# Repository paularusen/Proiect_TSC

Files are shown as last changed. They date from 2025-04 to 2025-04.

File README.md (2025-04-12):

## Descrierea produsului

  Proiectul este centrat pe microcontrolerul ```ESP32-C6```, care, datorită versatilității sale, suportă comunicații Wi‑Fi 6, 
Bluetooth și IEEE 802.15.4, alături de multiple interfețe periferice. Designul integrează un e‑paper display, un modul SD 
card, memorie flash externă, un modul RTC și interfețe de comunicație (```USB```, ```UART```, ```I2C```). Fiecare interfață este atribuită 
unor pini specifici pentru a asigura o separare clară a funcțiilor, evitând conflictele și maximizând performanța și
eficiența energetică.

## Diagrama bloc

Diagrama_bloc

## Descrierea componentelor și a pinilor utilizați

### ESP32-C6 – Microcontrolerul Central
Rol: Coordonează toate operațiunile sistemului și gestionează comunicațiile cu toate modulele periferice.
Pini atribuiți:

	- GND: 1 si 28
	- 3V3: 2
	- RESET: 3
	- SS_SD: 4
	- EPD_DC: 5
	- SCK: 6
	- MOSI: 7
	- INT_RTC: 8
	- 32KHZ: 9
	- GPIO8: 10
	- EPD_CS: 11
	- FLASH_CS: 12
	- USB_D-: 13
	- USB_D+: 14
	- IO/BOOT: 15
	- RTC_RST: 16
	- I2C_PW: 17
	- EPD_3V3_C: 18
	- SDA: 19
	- SCL: 20
	- EPD_RST: 21
	- IO/CHANGE: 23
	- RX: 24
	- TX: 25
	- EPD_BUSY: 26
	- MISO: 27

Rolul fiecărui pin va fi detaliat în cadrul componentelor, în următoarele rânduri.

### E‑Paper Display
Rol: Afișare informații într-un mod foarte eficient energetic, potrivit pentru aplicații de tip IoT sau afișaje statice.
Pini atribuiți:

	- EPD_DC: Selectează între modurile de comandă și de date pentru e-paper.
	- EPD_CS: Chip Select – activează comunicația cu e‑paper-ul.
	- EPD_RST: Linie de reset, esențială la inițializare pentru afișaj.
	- EPD_BUSY: Semnal de status ce indică dacă afișajul este ocupat (prevenind suprascrierea datelor).
	- EPD_3V3_C: Linia de alimentare dedicată, asigurând o tensiune stabilă și izolată pentru e‑paper.

### Modul SD Card
Rol: Stocare de date suplimentare (fișiere de sistem, date utilizator etc.)
Pini atribuiți:

	- SS_SD: Chip select specific pentru SD Card, activând modulul numai atunci când este necesar.
	- SCK: Linia de ceas pentru comunicațiile SPI.
	- MOSI: Linia de ieșire de date dinspre ESP32 către SD Card.
	- MISO: Linia de intrare de date, pentru citirea informațiilor de la SD Card.

### Memorie Flash Externă
Rol: Stocarea firmware-ului sau a datelor critice ce necesită o capacitate suplimentară față de memoria internă.
Pini atribuiți:

	- FLASH_CS: Chip select pentru memorie flash, pentru a activa comunicația doar atunci când este necesar.

### Modul RTC (Real-Time Clock)
Rol: Asigură o cronometrare precisă, utilă pentru funcții de alarmă, logare a datelor sau sincronizare de timp în 
aplicații IoT.
Pini atribuiți:

	- INT_RTC: Întrerupere de la RTC, notificând microcontrolerul despre evenimente (ex. alarmă).
	- RTC_RST: Linia de reset pentru modulul RTC, asigurând reinițializarea corectă a ceasului.
	- 32KHZ: Furnizează un semnal de 32 kHz, esențial pentru funcționarea precisă a RTC-ului.

### Senzorul de mediu (ex.: BME688):
Rol: Măsoară parametri esențiali precum temperatura, umiditatea, presiunea atmosferică și compoziția gazelor din mediul 
înconjurător.
Comunicarea se realizează prin magistrala I2C, utilizând SDA(linia de date I2C), SCL(linia de ceas I2C) și I2C_PW.

### Interfața I2C
Rol: Comunicare cu senzori, module de monitorizare a bateriei, eventual RTC suplimentar sau alte periferice cu consum 
redus.
Pini atribuiți:

	- SDA: Linia de date pentru comunicația I2C.
	- SCL: Linia de ceas pentru I2C.
	- I2C_PW: Poate fi folosit pentru a activa sau alimenta circuitele periferice I2C (ex. senzori sau monitor de baterie).

### Interfața USB
Rol: Programare, transfer de date sau alimentare în anumite condiții.
Pini atribuiți:

	- USB_D- și USB_D+: Linii diferențiale pentru comunicația USB.

### Interfața UART
Rol: Comunicații seriale pentru debugging, logare sau control extern.
Pini atribuiți:

	- RX: Recepție UART.
	- TX: Transmisie UART.

Pinii speciali precum IO/BOOT și IO/CHAGE permit configurarea modului de pornire și monitorizarea încărcării, iar GP0IO8 
și GOL asigură flexibilitatea pentru extinderi viitoare.
	IO/BOOT: utilizat la pornirea sistemului pentru selectarea modului de boot. Această funcție este esențială pentru a 
intra în modul de programare sau diagnosticare, conform cerințelor de firmware.
	IO/CHAGE: dedicat monitorizării stării de încărcare a sistemului. Acest pin poate fi legat la un circuit de detecție al 
încărcării bateriei sau indicator LED pentru a semnala starea de încărcare.
	GP0IO8: un GPIO general care poate fi folosit pentru extinderi ulterioare (ex. conectarea unui senzor adițional, trigger 
de eveniment etc.).
	Pin 22: funcționalitatea acestui pin poate fi folosită ca ieșire generală pentru semnale de control, cum ar fi activarea 
unor relee, indicatori LED suplimentari sau semnale de sincronizare pentru alte module.

## Consumul de Energie și comunicațiile

### Consumul microcontrolerului:
	- ESP32-C6 dispune de moduri de economisire a energiei (deep sleep) și este optimizat pentru aplicații IoT. Astfel, în 
condiții de standby consumul poate fi redus la câțiva microamperi.

### SPI și I2C:
	- Utilizarea magistralelor SPI (pentru SD Card, flash extern și e‑paper display) și I2C (pentru senzori și monitorizare 
baterie) permite un transfer de date rapid și eficient, dar și o separare logică care contribuie la reducerea 
interferențelor.

### USB și UART:
	- Aceste interfețe sunt folosite mai ales pentru debugging și programare. Deși USB poate implica un consum mai mare când 
este activ, acesta este activ doar în timpul programării sau transferurilor de date.

### Alimentare:
	- Pinul de 3V3) este utilizat pentru alimentarea ESP32-C6 și a modulelor critice, iar alocarea separată pentru EPD 
(EPD_3V3_C) asigură o tensiune stabilă pentru afișajul e-paper.

## Bill of Materials
| Componentă | Distribuitor | Datasheet |
| :--- | :--- | :--- |
| ESP32 C6| https://eu.mouser.com/ProductDetail/Espressif-Systems/ESP32-C6-WROOM-1U-N8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 | https://eu.mouser.com/datasheet/2/891/Espressif_Systems_7_11_2023_esp32_c6_wroom_1_wroom-3236277.pdf |
| BUTTON | https://www.digikey.ro/en/products/detail/bourns-inc/7914S-1-000E/2537971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 | https://www.bourns.com/docs/Product-Datasheets/7914.pdf |
| USB-C connector| https://eu.mouser.com/ProductDetail/Same-Sky/UJC-H-G-SMT-2-P6-TR?qs=IKkN%2F947nfApFV8T6rOqww%3D%3D |https://eu.mouser.com/datasheet/2/1628/ujc_h_g_smt_2_p6_tr-3511211.pdf |
| USBLC6-2SC6Y | https://eu.mouser.com/ProductDetail/STMicroelectronics/USBLC6-2SC6Y?qs=gNDSiZmRJS%2FOgDexvXkdow%3D%3D | https://eu.mouser.com/datasheet/2/389/usblc6_2sc6y-1852505.pdf |
| DMG2305UX-7 | https://eu.mouser.com/ProductDetail/Diodes-Incorporated/DMG2305UX-7?qs=L1DZKBg7t5F%2FNBHrjfxC%252Bg%3D%3D | https://www.diodes.com/assets/Datasheets/DMG2305UX.pdf |
| XC6220A331MR-G | https://eu.mouser.com/ProductDetail/Torex-Semiconductor/XC6220A331MR-G?qs=AsjdqWjXhJ8ZSWznL1J0gg%3D%3D | https://eu.mouser.com/datasheet/2/760/xc6220-3371556.pdf |
| SD0805S020S1R0 | https://eu.mouser.com/ProductDetail/KYOCERA-AVX/SD0805S020S1R0?qs=jCA%252BPfw4LHbpkAoSnwrdjw%3D%3D | https://eu.mouser.com/datasheet/2/40/schottky-3165252.pdf |
| 112A-TAAR-R03 | https://store.comet.srl.ro/Catalogue/Product/43497/ | https://store.comet.bg/download-file.php?id=27596 |
| 68uH inductance | https://eu.mouser.com/ProductDetail/Vishay-Dale/IFDC5050JZER680M?qs=iLKYxzqNS745SePZd8tBoA%3D%3D | https://www.vishay.com/docs/34635/ifdc5050jz.pdf |
| SI1308EDL-T1-GE3 | https://eu.mouser.com/ProductDetail/Vishay-Semiconductors/SI1308EDL-T1-GE3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 | https://www.vishay.com/docs/63399/si1308edl.pdf |
| MBR0530 | https://eu.mouser.com/ProductDetail/Micro-Commercial-Components-MCC/MBR0530-TP?qs=KFo7JewZbUECRHkxGanrdg%3D%3D | https://eu.mouser.com/datasheet/2/258/MBR0520_MBR0580_SOD123_-2492194.pdf |
| MCP73831 | https://eu.mouser.com/ProductDetail/Microchip-Technology/MCP73831-2ACI-MC?qs=hH%252BOa0VZEiBneYTVdpuVdg%3D%3D | https://eu.mouser.com/datasheet/2/268/MCP73831_Family_Data_Sheet_DS20001984H-3441711.pdf |
| BME688 | https://eu.mouser.com/ProductDetail/Bosch-Sensortec/BME688?qs=IS%252B4QmGtzzqQoVDscqwx3A%3D%3D | https://eu.mouser.com/datasheet/2/783/bst_bme688_fl000-2307034.pdf |
| FH34SRJ-24S-0.5SH(99) | https://eu.mouser.com/ProductDetail/Hirose-Connector/FH34SRJ-24S-0.5SH99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 | https://eu.mouser.com/datasheet/2/185/FH34SRJ_24S_0_5SH_99__CL0580_1255_6_99_2DDrawing_0-1615044.pdf |
| BD5229G-TR | https://eu.mouser.com/ProductDetail/ROHM-Semiconductor/BD5229G-TR?qs=4kLU8WoGk0vvnhrrYwdszw%3D%3D | https://fscdn.rohm.com/en/products/databook/datasheet/ic/power/voltage_detector/bd52xxg-e.pdf |
| MAX17048G+T10 | https://eu.mouser.com/ProductDetail/Analog-Devices-Maxim-Integrated/MAX17048G%2bT10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 | https://eu.mouser.com/datasheet/2/609/MAX17048_MAX17049-3469099.pdf |
| DS3231SN# | https://eu.mouser.com/ProductDetail/Analog-Devices-Maxim-Integrated/DS3231SN?qs=1eQvB6Dk1vhUlr8%2FOrV0Fw%3D%3D | https://eu.mouser.com/datasheet/2/609/DS3231-3421123.pdf |
| CPH3225A | https://eu.mouser.com/ProductDetail/Seiko-Semiconductors/CPH3225A?qs=3etwrb1wR%252BhUOph6lAO7eg%3D%3D | https://eu.mouser.com/datasheet/2/360/Seiko_Instruments_MicroBattery_E_20230330_2024Jan_-3561061.pdf |
| PFMF.050.1 | https://eu.mouser.com/ProductDetail/Schurter/PFMF.050.2?qs=1auRipcfynCums5v1iucSA%3D%3D | https://eu.mouser.com/datasheet/2/358/typ_PFMF-1275918.pdf |
| Qwiic | https://eu.mouser.com/ProductDetail/Adafruit/4208?qs=PzGy0jfpSMtbScLbr0L5dw%3D%3D | https://learn.adafruit.com/introducing-adafruit-stemma-qt/technical-specs |
| W25Q512JVEIQ | https://eu.mouser.com/ProductDetail/Winbond/W25Q512JVEIQ?qs=l7cgNqFNU1jw6svr3at6tA%3D%3D | https://eu.mouser.com/datasheet/2/949/Winbond_W25Q512JV_Datasheet-3240039.pdf |
| PGB1010603MR | https://eu.mouser.com/ProductDetail/Littelfuse/PGB1010603MR?qs=gu7KAQ731URLg4GSnNNN7Q%3D%3D | https://www.littelfuse.com/assetdocs/pulseguard-esd-suppressors-pgb1-datasheet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 |
| TANT Capacitor | https://eu.mouser.com/ProductDetail/KEMET/T491B107M006AT?qs=U312oeP%2FpiHOgyk6KO2m0g%3D%3D | https://www.vishay.com/docs/40002/293d.pdf |
| Capacitor 0.1uF | https://eu.mouser.com/ProductDetail/KYOCERA-AVX/KGF21BR71H104KT?qs=Jm2GQyTW%2FbjYyKCvVWAEOw%3D%3D | https://eu.mouser.com/datasheet/2/40/KGF-3223650.pdf |
| Capacitor 1uF | https://eu.mouser.com/ProductDetail/TAIYO-YUDEN/MAASL105CC7105MFCA01?qs=HFfMDpzxxd1Fn%2FInbJA7vw%3D%3D | https://eu.mouser.com/datasheet/2/396/TAIYO_YUDEN_04_27_2024_c_mlcc_A_e1-3451516.pdf |
| Capacitor 4.7uF | https://eu.mouser.com/ProductDetail/KYOCERA-AVX/CM05X5R475M16AH?qs=doiCPypUmgFT1xquZKhWtQ%3D%3D | https://eu.mouser.com/datasheet/2/40/Kyocera_AVX_Components_CM025_CM05_CM105_CM21_E217K-2932876.pdf |
| Capacitor 10 uF | https://eu.mouser.com/ProductDetail/TDK/CGA3EDX7T1A106M080AU?qs=ZcfC38r4PovL%2FBNBUzzBFw%3D%3D | https://product.tdk.com/system/files/dam/doc/product/capacitor/ceramic/mlcc/catalog/mlcc_automotive_general_en.pdf |
| Capacitor 100nF | https://eu.mouser.com/ProductDetail/KYOCERA-AVX/KAM21BR71H104JT?qs=Jm2GQyTW%2Fbic6Zk4McEt6w%3D%3D | https://eu.mouser.com/datasheet/2/40/AutoMLCCKAM-3216307.pdf |
| Resistor 0.47 | https://eu.mouser.com/ProductDetail/SEI-Stackpole/RNCL1210FT50L0?qs=17ckDYBRdelVLOJ%252BDFjlUw%3D%3D | https://eu.mouser.com/datasheet/2/385/sei_rncl-3223524.pdf |
| Resistor 2.2 | https://eu.mouser.com/ProductDetail/YAGEO/RT1206FRE072R2L?qs=XhSZopxZ3H6S0nYZD83pAA%3D%3D | https://eu.mouser.com/datasheet/2/447/PYu_RT_1_to_0_01_RoHS_L_15-3461507.pdf |
| Resistor 15 | https://eu.mouser.com/ProductDetail/Panasonic/ERA-6AHD150V?qs=MNPzkKEzRtQip8ZeekU%252BRw%3D%3D | https://industrial.panasonic.com/cdbs/www-data/pdf/RDM0000/AOA0000C307.pdf |
Resistor 200 | https://eu.mouser.com/ProductDetail/TE-Connectivity-Holsworthy/RP73C2B200RFTDF?qs=n4i9pByFsMR0dWGpf721CA%3D%3D | https://eu.mouser.com/datasheet/2/418/10/ENG_DS_1773272_M1-1588495.pdf |
| Resistor 2k | https://eu.mouser.com/ProductDetail/Panasonic/ERA-3AED202V?qs=yocZuyCaXdM2cBmjcGkIyA%3D%3D | https://industrial.panasonic.com/cdbs/www-data/pdf/RDM0000/AOA0000C307.pdf |
| Resistor 5k1 | https://eu.mouser.com/ProductDetail/Vishay-Beyschlag/MCS04020C5101FE000?qs=wTZ%2FFzl837YsKPLPRIXUbg%3D%3D | https://www.vishay.com/docs/28705/mcx0x0xpro.pdf |
| Resistor 10k | https://eu.mouser.com/ProductDetail/SEI-Stackpole/RNWA0612BTE10K0?qs=IKkN%2F947nfD62pDKWE9ZTQ%3D%3D | https://eu.mouser.com/datasheet/2/385/SEI_RNWA-3473840.pdf |
| Resistor 100K | https://eu.mouser.com/ProductDetail/Panasonic/ERA-3AED104V?qs=MNPzkKEzRtQIWcmUWL4kjg%3D%3D | https://industrial.panasonic.com/cdbs/www-data/pdf/RDM0000/AOA0000C307.pdf |
| E-Paper Display | https://eu.mouser.com/ProductDetail/Microtips-Technology/MT-DEPG0750BNU590F1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| https://eu.mouser.com/datasheet/2/271/MT_DEPG0750BNU590F1_V2_7-1894282.pdf |
| LP584174 Battery| https://www.tme.eu/en/details/accu-lp584174_cl/rechargeable-batteries/cellevia-batteries/l584174/ | https://www.tme.eu/Document/e0683d8c34e6d878124489f71bffb6ee/cel0014.pdf |

## Observații
- Am modificat footprint-ul componentei J2, prin mutarea pad-urilor GND, VUSB și B8 cu câțiva mm spre stânga, pentru a corecta eroarea ”SMD Hole”.

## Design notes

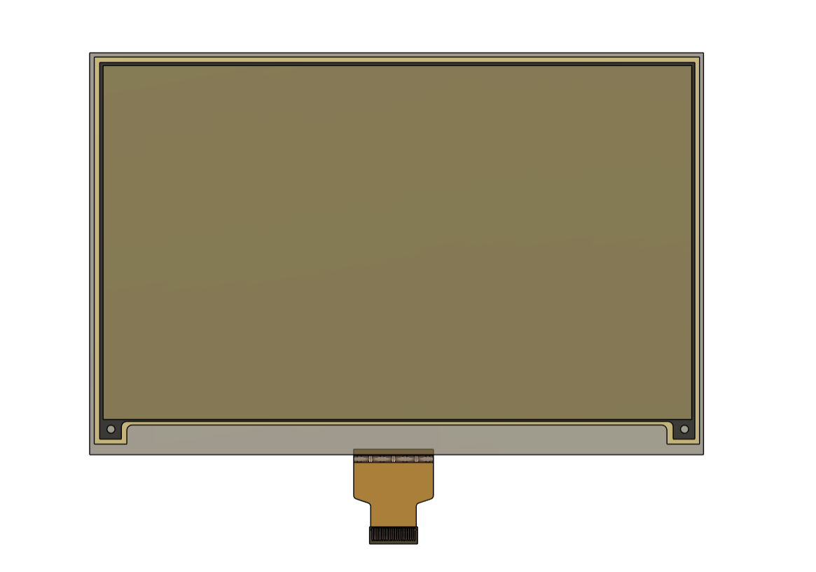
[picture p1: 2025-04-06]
Images/display_back.png

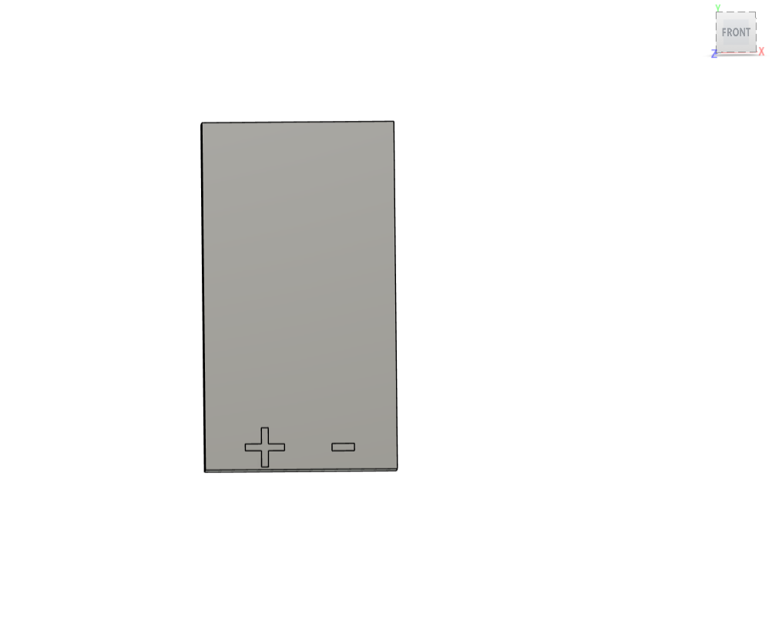
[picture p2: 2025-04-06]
Images/battery.png

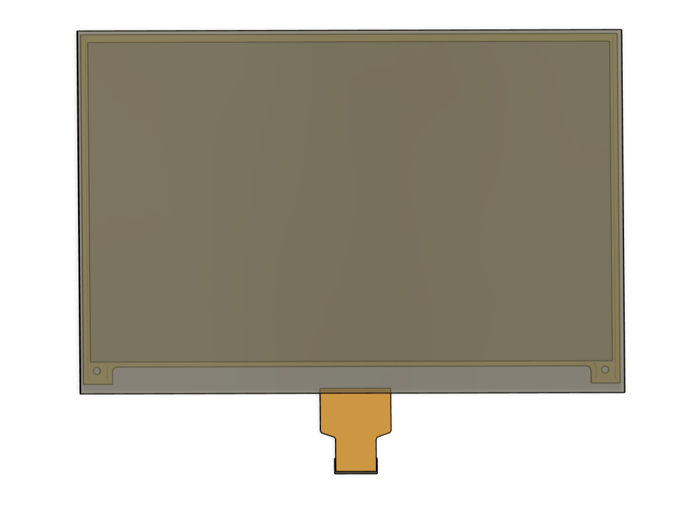
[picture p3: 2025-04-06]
Images/display_front.png

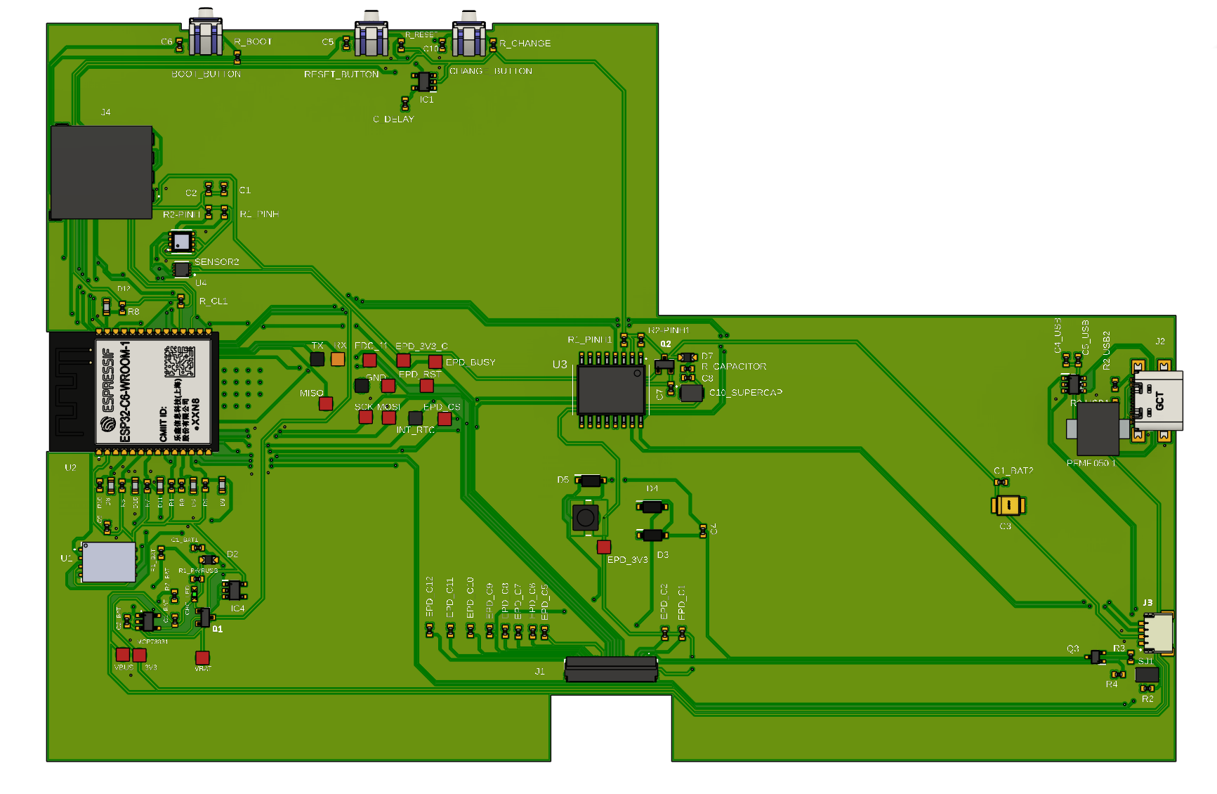
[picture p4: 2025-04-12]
Images/3D_board.png

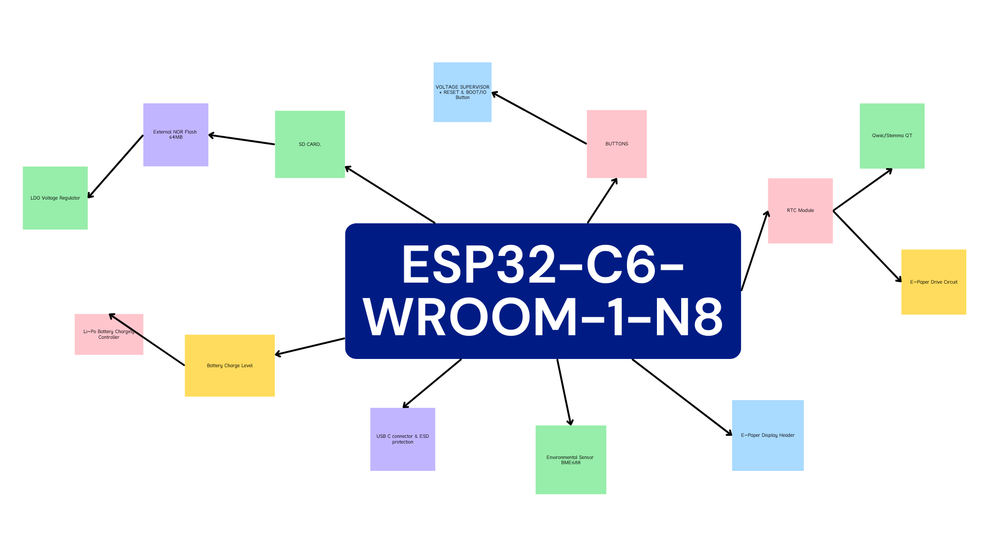
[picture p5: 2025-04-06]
Images/Diagrama_bloc.png

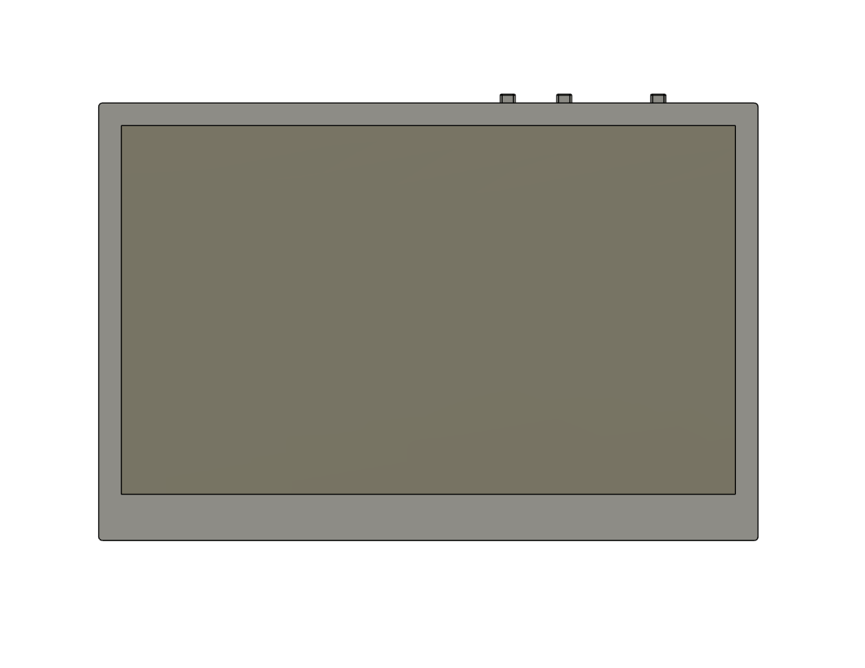
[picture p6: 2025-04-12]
Images/3D_device.png

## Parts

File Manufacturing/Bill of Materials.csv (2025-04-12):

Qty | Value | Device | Package | Parts | Description | ARROW_PART_NUMBER | ARROW_PRICE-STOCK | AVAILABILITY | CENTROID_NOT_SPECIFIED | CHECK_PRICES | COPYRIGHT | DATASHEET | DESCRIPTION | DIGIKEY_DESCRIPTION | DIGIKEY_PART_NUMBER | HEIGHT | LEAD_FREE | MANUFACTURER_NAME | MANUFACTURER_PART_NUMBER | MF | MFR_NAME | MOUSER_PART_NUMBER | MOUSER_PRICE-STOCK | MOUSER_TESTING_PART_NUMBER | MOUSER_TESTING_PRICE-STOCK | MP | MPN | PACKAGE | POPULARITY | PREFIX | PRICE | PROD_ID | PURCHASE-URL | ROHS | SNAPEDA_LINK | SPICEMODEL | SPICEPREFIX | TEMPERATURE_RANGE_HIGH | TEMPERATURE_RANGE_LOW | TP_SIGNAL_NAME | VALUE
1 |  | ADAFRUIT_LEDCHIP-LED0603 | ADAFRUIT_CHIP-LED0603 | CHG_LED | LED
1 |  | ESP32_WROVER_EAGLE-LTSPICE_RR0402 | ESP32_WROVER_EAGLE-LTSPICE_R0402 | R_CAPACITOR | RESISTOR, European symbol |  |  |  |  |  |  |  |  |  |  |  |  |  |  |  |  |  |  |  |  |  |  |  |  |  |  |  |  |  |  | NONE | R
1 | 0 | SJ | SJ | SJ1 | SMD solder JUMPER |  |  |  |  |  |  |  |  |  |  |  |  |  |  |  |  |  |  |  |  |  |  |  | 3
1 | 0.1uF/50V | ESP32_WROVER_EAGLE-LTSPICE_CC0402 | ESP32_WROVER_EAGLE-LTSPICE_C0402 | EPD_C5 | CAPACITOR, European symbol |  |  |  |  |  |  |  |  |  |  |  |  |  |  |  |  |  |  |  |  |  |  |  |  |  |  |  |  |  |  | NONE | C
1 | 0.47 | ESP32_WROVER_EAGLE-LTSPICE_RR0402 | ESP32_WROVER_EAGLE-LTSPICE_R0402 | R3 | RESISTOR, European symbol |  |  |  |  |  |  |  |  |  |  |  |  |  |  |  |  |  |  |  |  |  |  |  |  |  |  |  |  |  |  | NONE | R
1 | 100K | ESP32_WROVER_EAGLE-LTSPICE_RR0402 | ESP32_WROVER_EAGLE-LTSPICE_R0402 | R1_PWRUSB | RESISTOR, European symbol |  |  |  |  |  |  |  |  |  |  |  |  |  |  |  |  |  |  |  |  |  |  |  |  |  |  |  |  |  |  | NONE | R
1 | 100nF | EAGLE-LTSPICE_CC0402 | EAGLE-LTSPICE_C0402 | C4_USB | CAPACITOR, European symbol |  |  |  |  |  |  |  |  |  |  |  |  |  |  |  |  |  |  |  |  |  |  |  |  |  |  |  |  |  |  | NONE | C
7 | 100nF | ESP32_WROVER_EAGLE-LTSPICE_CC0402 | ESP32_WROVER_EAGLE-LTSPICE_C0402 | C1, C2, C6, C8, C9, C10, C_DELAY | CAPACITOR, European symbol |  |  |  |  |  |  |  |  |  |  |  |  |  |  |  |  |  |  |  |  |  |  |  |  |  |  |  |  |  |  | NONE | C
1 | 100uF | RCL_CPOL-EUCT3528 | RCL_CT3528 | C3 | POLARIZED CAPACITOR, European symbol |  |  |  |  |  |  |  |  |  |  |  |  |  |  |  |  |  |  |  |  |  |  |  | 0 |  |  |  |  |  |  |  | C
16 | 10K | ESP32_WROVER_EAGLE-LTSPICE_RR0402 | ESP32_WROVER_EAGLE-LTSPICE_R0402 | R1, R1_PINH, R1_PINH1, R2-PINH, R2-PINH1, R4, R5, R6, R7, R8, R9, R10, R_BOOT, R_CHANGE, R_CL1, R_RESET | RESISTOR, European symbol |  |  |  |  |  |  |  |  |  |  |  |  |  |  |  |  |  |  |  |  |  |  |  |  |  |  |  |  |  |  | NONE | R
1 | 10uF | ESP32_WROVER_EAGLE-LTSPICE_CC0402 | ESP32_WROVER_EAGLE-LTSPICE_C0402 | C7 | CAPACITOR, European symbol |  |  |  |  |  |  |  |  |  |  |  |  |  |  |  |  |  |  |  |  |  |  |  |  |  |  |  |  |  |  | NONE | C
1 | 112A-TAAR-R03_ATTEND | 112A-TAAR-R03_ATTEND | 112ATAARR03ATTEND | J4 | Micro SD Card Socket, Push-Push Type, Top Mount, SMT, H=1.83mm, 10u |  |  |  |  |  |  |  | Micro SD Card Socket | Push-Push Type | Top Mount | SMT | H=1.83mm | 10u |  |  | 1.9mm |  | ATTEND | 112A-TAAR-R03 ATTEND
1 | 1uF | ESP32_WROVER_EAGLE-LTSPICE_CC0402 | ESP32_WROVER_EAGLE-LTSPICE_C0402 | C5 | CAPACITOR, European symbol |  |  |  |  |  |  |  |  |  |  |  |  |  |  |  |  |  |  |  |  |  |  |  |  |  |  |  |  |  |  | NONE | C
9 | 1uF/50V | ESP32_WROVER_EAGLE-LTSPICE_CC0402 | ESP32_WROVER_EAGLE-LTSPICE_C0402 | EPD_C1, EPD_C2, EPD_C6, EPD_C7, EPD_C8, EPD_C9, EPD_C10, EPD_C11, EPD_C12 | CAPACITOR, European symbol |  |  |  |  |  |  |  |  |  |  |  |  |  |  |  |  |  |  |  |  |  |  |  |  |  |  |  |  |  |  | NONE | C
1 | 2.2 | ESP32_WROVER_EAGLE-LTSPICE_RR0402 | ESP32_WROVER_EAGLE-LTSPICE_R0402 | R2 | RESISTOR, European symbol |  |  |  |  |  |  |  |  |  |  |  |  |  |  |  |  |  |  |  |  |  |  |  |  |  |  |  |  |  |  | NONE | R
1 | 200 | ESP32_WROVER_EAGLE-LTSPICE_RR0402 | ESP32_WROVER_EAGLE-LTSPICE_R0402 | R1_BAT | RESISTOR, European symbol |  |  |  |  |  |  |  |  |  |  |  |  |  |  |  |  |  |  |  |  |  |  |  |  |  |  |  |  |  |  | NONE | R
2 | 20V/4.2A/52mO/1.4W | ESP32_WROVER_SPARKFUN-DISCRETESEMI_MOSFET_PCH-DMG2305UX-7 | ESP32_WROVER_SPARKFUN-DISCRETESEMI_SOT23-3 | Q1, Q2 | P-channel MOSFETs |  |  |  |  |  |  |  |  |  |  |  |  |  |  |  |  |  |  |  |  |  |  |  |  |  |  | TRAN-14388 |  |  |  |  |  |  |  |  | 20V/4.2A/52mO/1.4W
1 | 2K | ESP32_WROVER_EAGLE-LTSPICE_RR0402 | ESP32_WROVER_EAGLE-LTSPICE_R0402 | R2_BAT | RESISTOR, European symbol |  |  |  |  |  |  |  |  |  |  |  |  |  |  |  |  |  |  |  |  |  |  |  |  |  |  |  |  |  |  | NONE | R
1 | 4.7uF | EAGLE-LTSPICE_CC0402 | EAGLE-LTSPICE_C0402 | C5_USB | CAPACITOR, European symbol |  |  |  |  |  |  |  |  |  |  |  |  |  |  |  |  |  |  |  |  |  |  |  |  |  |  |  |  |  |  | NONE | C
4 | 4.7uF | ESP32_WROVER_EAGLE-LTSPICE_CC0402 | ESP32_WROVER_EAGLE-LTSPICE_C0402 | C1_BAT, C1_BAT1, C1_BAT2, C2_BAT | CAPACITOR, European symbol |  |  |  |  |  |  |  |  |  |  |  |  |  |  |  |  |  |  |  |  |  |  |  |  |  |  |  |  |  |  | NONE | C
1 | 4.7uF/25V | ESP32_WROVER_EAGLE-LTSPICE_CC0402 | ESP32_WROVER_EAGLE-LTSPICE_C0402 | C4 | CAPACITOR, European symbol |  |  |  |  |  |  |  |  |  |  |  |  |  |  |  |  |  |  |  |  |  |  |  |  |  |  |  |  |  |  | NONE | C
2 | 5k1 | ESP32_WROVER_EAGLE-LTSPICE_RR0402 | ESP32_WROVER_EAGLE-LTSPICE_R0402 | R2-USB1, R2-USB2 | RESISTOR, European symbol |  |  |  |  |  |  |  |  |  |  |  |  |  |  |  |  |  |  |  |  |  |  |  |  |  |  |  |  |  |  | NONE | R
1 | 68uH | 744043680IND_4828-WE-TPC_WRE | IND_4828-WE-TPC_WRE | L1 |  |  |  |  |  |  | Copyright (C) 2024 Ultra Librarian. All rights reserved. |  |  |  |  |  |  |  | 744043680 |  | Wurth Electronics
1 | BD5229G-TR | BD5229G-TR | SOT95P280X125-5N | IC1 | Voltage Detector with Adjustable Delay Time: CMOS processes are utilized to develop high precision, low current consumption CMOS reset ICs that allow arbitrary setting of the delay time. The extensive lineup includes both Nch Open Drain and CMOS output types in a wide range of detection voltages (from 2.3V to 6.0V, in 0.1V steps), enabling selection of the ideal solution based on customer requirements. In addition, the entire series is of course both lead-free and RoHS-compliant. |  |  |  |  |  |  |  | Voltage Detector with Adjustable Delay Time: CMOS processes are utilized to develop high precision | low current consumption CMOS reset ICs that allow arbitrary setting of the delay time. The extensive lineup includes both Nch Open Drain and CMOS output types in a wide range of detection voltages (from 2.3V to 6.0V | in 0.1V steps) | enabling selection of the ideal solution based on customer requirements. In addition | the entire series is of course both lead-free and RoHS-compliant. |  |  | 1.25mm |  | ROHM Semiconductor | BD5229G-TR |  |  | 755-BD5229G-TR | https://www.mouser.co.uk/ProductDetail/ROHM-Semiconductor/BD5229G-TR?qs=4kLU8WoGk0vvnhrrYwdszw%3D%3D
1 | BME688 | ESP32_WROVER_BME680_BME680 | ESP32_WROVER_BME680_PSON80P300X300X100-8N | SENSOR2 | Integrated Environmental Unit |  |  | Unavailable |  |  |  |  | Integrated Environmental Unit |  |  |  |  |  |  | Bosch Sensortec |  |  |  |  |  | BME680 |  | LGA-8 Bosch Tools |  |  | None
2 | BUTTON_CUSYOMV1 | BUTTON_CUSYOMV1 | MYBUTTON | BOOT_BUTTON, RESET_BUTTON
1 | CHANGE_BUTTON | BUTTON_CUSYOMV1 | MYBUTTON | CHANGE_BUTTON
1 | CPH3225A | CPH3225A | CAPCP3225X100N | C10_SUPERCAP | Cap 0.011F 3.3V 1210 Flat Check availability |  |  | Not in stock |  | https://www.snapeda.com/parts/CPH3225A/Seiko+Instruments/view-part/?ref=eda |  |  | 11 mF (EDLC) Supercapacitor 3.3 V 1210 (3225 Metric) - - |  |  |  |  |  |  | Seiko Instruments |  |  |  |  |  | CPH3225A |  | 1210 Seiko |  |  | None |  | https://www.snapeda.com/api/url_track_click_mouser/?unipart_id=562593&manufacturer=Seiko Instruments&part_name=CPH3225A&search_term=None |  | https://www.snapeda.com/parts/CPH3225A/Seiko+Instruments/view-part/?ref=snap
1 | DS3231SN# | DS3231SN# | SOIC127P1032X265-16N | U3 | Real Time Clock Serial 16-Pin SOIC W T/R Check availability |  |  | In Stock |  | https://www.snapeda.com/parts/DS3231SN%23/Analog+Devices/view-part/?ref=eda |  |  | Extremely Accurate I²C-Integrated RTC/TCXO/Crystal |  |  |  |  |  |  | Analog Devices |  |  |  |  |  | DS3231SN# |  | SOIC-16 Maxim |  |  | None |  | https://www.snapeda.com/api/url_track_click_mouser/?unipart_id=99048&manufacturer=Analog Devices&part_name=DS3231SN#&search_term=None |  | https://www.snapeda.com/parts/DS3231SN%23/Analog+Devices/view-part/?ref=snap
1 | ESP32-C6-WROOM-1-N8 | ESP32-C6-WROOM-1-N8 | XCVR_ESP32-C6-WROOM-1-N8 | U2 | Check availability |  |  | In Stock |  | https://www.snapeda.com/parts/ESP32-C6-WROOM-1-N8/Espressif+Systems/view-part/?ref=eda |  |  | Multiprotocol Modules ESP32-C6 module | Wi-Fi 6 in 2.4 GHz band | Bluetooth 5 | Zigbee 3.0 and Thread. ESP34-WROOM Compatible - ENGINEERING SAMPLE |  |  |  |  |  |  | Espressif Systems |  |  |  |  |  | ESP32-C6-WROOM-1-N8 |  | None |  |  | None |  |  |  | https://www.snapeda.com/parts/ESP32-C6-WROOM-1-N8/Espressif+Systems/view-part/?ref=snap
1 | ESP32C6_VARISTORCN1812 | ESP32C6_VARISTORCN1812 | ESP32C6_VARISTOR_CT/CN1812 | PFMF.050.1 | VARISTOR |  |  |  |  |  |  |  |  |  |  |  |  |  |  |  |  |  |  |  |  |  |  |  | 0
1 | ESP32_WROVER_AVX---SD0805S020S1R0_AVX_SD0805S020S1R0_0_0AVX_SD0805S020S1R0_0_0 | ESP32_WROVER_AVX---SD0805S020S1R0_AVX_SD0805S020S1R0_0_0AVX_SD0805S020S1R0_0_0 | ESP32_WROVER_AVX---SD0805S020S1R0_AVX_SD0805S020S1R0_0 | D2 | Schottky Barrier Rectifier Diode |  |  |  | No |  |  | http://datasheets.avx.com/schottky.pdf |  | DIODE SCHOTTKY 20V 1A 0805 | 478-7800-1-ND |  | yes |  |  | AVX |  | 581-SD0805S020S1R0 |  |  |  |  |  | 0805 (2012 metric) |  | D |  |  |  | yes |  |  |  | +125°C | -55°C
1 | FH34SRJ-24S-0.5SH_99_ | FH34SRJ-24S-0.5SH_99_ | FH34SRJ24S05SH99 | J1 | (0.50mm) Surface Mount, Right Angle |  |  |  |  |  |  |  | 24 Position FFC | FPC Connector Contacts | (0.50mm) Surface Mount | Right Angle |  |  | 1.1mm |  | Hirose | FH34SRJ-24S-0.5SH(99) |  |  | 798-FH34SRJ24S05SH99 | https://www.mouser.co.uk/ProductDetail/Hirose-Connector/FH34SRJ-24S-0.5SH99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
1 | MAX17048G+T10 | MAX17048G+T10 | SON50P200X200X80-9N | U4 | Check availability |  |  | In Stock |  | https://www.snapeda.com/parts/MAX17048G+T10/Analog+Devices/view-part/?ref=eda |  |  | 3µA 1-Cell/2-Cell Fuel Gauge with ModelGauge |  |  |  |  |  |  | Analog Devices |  |  |  |  |  | MAX17048G+T10 |  | TDFN-8 Maxim |  |  | None |  | https://www.snapeda.com/api/url_track_click_mouser/?unipart_id=329239&manufacturer=Analog Devices&part_name=MAX17048G+T10&search_term=None |  | https://www.snapeda.com/parts/MAX17048G+T10/Analog+Devices/view-part/?ref=snap
3 | MBR0530 | MBR0530 | SOD3716X135N | D3, D4, D5 | ON SEMICONDUCTOR - MBR0530 - DIODE, SCHOTTKY, 0.5A, 30V, SOD-123 |  |  | In Stock |  | https://www.snapeda.com/parts/MBR0530/Onsemi/view-part/?ref=eda |  |  | Diode Schottky 30 V 500mA Surface Mount SOD-123 |  |  |  |  |  |  | ON Semiconductor |  |  |  |  |  | MBR0530 |  | SOD-123-2 ON Semiconductor |  |  | None |  | https://www.snapeda.com/api/url_track_click_mouser/?unipart_id=179458&manufacturer=ON Semiconductor&part_name=MBR0530&search_term=None |  | https://www.snapeda.com/parts/MBR0530/Onsemi/view-part/?ref=snap
1 | MCP73831 | ESP32_WROVER_SPARKFUN-IC-POWER_MCP73831 | ESP32_WROVER_SPARKFUN-IC-POWER_SOT23-5 | MCP73831 | MCP73831T Li-Ion, Li-Pol Controller |  |  |  |  |  |  |  |  |  |  |  |  |  |  |  |  |  |  |  |  |  |  |  |  |  |  | IC-09995
6 | PGB1010603MR | PGB1010603MR | DIOC1608X36N | D6, D8, D9, D10, D11, D12 | Check availability |  |  | In Stock |  | https://www.snapeda.com/parts/PGB1010603MR/Littelfuse/view-part/?ref=eda |  |  | 150V (Typ) Clamp - Ipp Tvs Diode Surface Mount 0603 (1608 Metric) |  |  |  |  |  |  | Littelfuse Inc. |  |  |  |  |  | PGB1010603MR |  | 0603 Littelfuse Inc. |  |  | None |  | https://www.snapeda.com/api/url_track_click_mouser/?unipart_id=5659453&manufacturer=Littelfuse Inc.&part_name=PGB1010603MR&search_term=None |  | https://www.snapeda.com/parts/PGB1010603MR/Littelfuse/view-part/?ref=snap
1 | QWIIC_RIGHT_ANGLE | QWIIC_CONNECTORJS-1MM | JST04_1MM_RA | J3 | SparkFun I2C Standard Qwiic Connector |  |  |  |  |  |  |  |  |  |  |  |  |  |  |  |  |  |  |  |  |  |  |  |  |  |  | CONN-13694 |  |  |  |  |  |  |  |  | QWIIC_RIGHT_ANGLE
1 | SAMACSYS_PARTS_USB4110-GF-A | SAMACSYS_PARTS_USB4110-GF-A | SAMACSYS_PARTS_USB4110GFA | J2 | CONN USB 2.0 TYPE-C R/A SMT |  |  |  |  |  |  |  | CONN USB 2.0 TYPE-C R/A SMT |  |  | 3.26mm |  | GCT (GLOBAL CONNECTOR TECHNOLOGY) | USB4110-GF-A |  |  | 640-USB4110-GF-A | https://www.mouser.co.uk/ProductDetail/GCT/USB4110-GF-A?qs=KUoIvG%2F9IlYiZvIXQjyJeA%3D%3D
1 | SD0805S020S1R0 | ESP32_WROVER_AVX---SD0805S020S1R0_AVX_SD0805S020S1R0_0_0AVX_SD0805S020S1R0_0_0 | ESP32_WROVER_AVX---SD0805S020S1R0_AVX_SD0805S020S1R0_0 | D7 | Schottky Barrier Rectifier Diode |  |  |  | No |  |  | http://datasheets.avx.com/schottky.pdf |  | DIODE SCHOTTKY 20V 1A 0805 | 478-7800-1-ND |  | yes |  |  | AVX |  | 581-SD0805S020S1R0 |  |  |  |  |  | 0805 (2012 metric) |  | D |  |  |  | yes |  |  |  | +125°C | -55°C
1 | SI1308EDL-T1-GE3 | SI1308EDL-T1-GE3 | SOT65P210X110-3N | Q3 | MOSFET N-Ch 30V 1.5A TrenchFET SC70 Vishay Si1308EDL-T1-GE3 N-channel MOSFET Transistor, 1.5 A, 30 V, 3-Pin SC-70 |  |  | In Stock |  | https://www.snapeda.com/parts/SI1308EDL-T1-GE3/Vishay+Siliconix/view-part/?ref=eda |  |  | Si1308EDL-T1-GE3 N-channel MOSFET Transistor | 1.5 A | 30 V | 3-Pin SC-70 | Siliconix / Vishay SI1308EDL-T1-GE3 |  |  |  |  |  |  | Vishay Siliconix |  |  |  |  |  | SI1308EDL-T1-GE3 |  | SOT-323 Vishay Semiconductor |  |  | None |  | https://www.snapeda.com/api/url_track_click_mouser/?unipart_id=274603&manufacturer=Vishay Siliconix&part_name=SI1308EDL-T1-GE3&search_term=None |  | https://www.snapeda.com/parts/SI1308EDL-T1-GE3/Vishay+Siliconix/view-part/?ref=snap
17 | TPTP20R | TPTP20R | TP20R | TP1, TP2, TP3, TP4, TP5, TP6, TP7, TP8, TP9, TP10, TP11, TP12, TP13, TP14, TP15, TP16, TP17 | Test pad |  |  |  |  |  |  |  |  |  |  |  |  |  |  |  |  |  |  |  |  |  |  |  | 2
1 | USBLC6-2SC6Y | USBLC6-2SC6Y | SOT95P280X145-6N | D1 | Low Cap. ESD Protection Auto SOT-23-6 STMicroelectronics USBLC6-2SC6Y, Dual Uni-Directional TVS Diode Array, 6-Pin SOT-23 |  |  | In Stock |  | https://www.snapeda.com/parts/USBLC6-2SC6Y/STMicroelectronics/view-part/?ref=eda |  |  | 17V Clamp 5A (8/20µs) Ipp Tvs Diode Surface Mount SOT-23-6 |  |  |  |  |  |  | STMicroelectronics |  |  |  |  |  | USBLC6-2SC6Y |  | SOT-23-6 STMicroelectronics |  |  | None |  |  |  | https://www.snapeda.com/parts/USBLC6-2SC6Y/STMicroelectronics/view-part/?ref=snap
1 | W25Q512JVEIQ | W25Q512JVEIQ | SON127P600X800X80-9N | U1 | Check availability |  |  | In Stock |  | https://www.snapeda.com/parts/W25Q512JVEIQ/Winbond+Electronics/view-part/?ref=eda |  |  | FLASH - NOR Memory IC 512Mb (64M x 8) SPI - Quad I/O 133 MHz 8-WSON (8x6) |  |  |  |  |  |  | Winbond Electronics |  |  |  |  |  | W25Q512JVEIQ |  | Package |  |  | None |  |  |  | https://www.snapeda.com/parts/W25Q512JVEIQ/Winbond+Electronics/view-part/?ref=snap
1 | XC6220A331MR-G | XC6220A331MR-G | SOT95P280X120-5N | IC4 | LDO Voltage Regulators |  |  |  |  |  |  |  | LDO Voltage Regulators |  |  | 1.2mm |  | Torex | XC6220A331MR-G |  |  | 865-XC6220A331MR-G | https://www.mouser.co.uk/ProductDetail/Torex-Semiconductor/XC6220A331MR-G?qs=AsjdqWjXhJ8ZSWznL1J0gg%3D%3D

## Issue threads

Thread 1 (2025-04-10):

[Schematic] Valoare R_CAPACITOR

tudorz23, 2025-04-10:
R_CAPACITOR nu are valoarea trecuta. Ar trebui sa fie 15.

paularusen, 2025-04-11:
Mulțumesc! Am rezolvat această problemă.

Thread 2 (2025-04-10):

[PCB] Unghiuri de 90 de grade

tudorz23, 2025-04-10:
Proiectul evita bine unghiurile de 90 de grade la trasee, dar exista 4 scapari:
1. La traseul "VBUS", langa piesa U1 (stanga jos)

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

2. La traseul "RESE", langa piesa R3 (dreapta jos)

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

3. La traseul "N$1", langa piesa R2-USB1 (dreapta sus)

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

4. La traseul "VUSB", langa piesa J2 (dreapta sus)

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

paularusen, 2025-04-11:
Mulțumesc pentru observații!

Closed 2025-04-11.

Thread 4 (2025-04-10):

[PCB] Nume componente pe SilkScreen

tudorz23, 2025-04-10:
Numele celor trei butoane si ale altor piese din zona lor sunt plasate in afara PCB-ului, astfel ca nu sunt vizibile pe modelul 3D.
De asemenea, pentru componentele din jurul lui U1, exista unele suprapuneri de nume. Desi piesele sunt apropiate si nu este mult spatiu la dispozitie pentru nume, sugerez un font mai mic, poate vor incapea mai bine.

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

paularusen, 2025-04-11:
Done!

Closed 2025-04-11.

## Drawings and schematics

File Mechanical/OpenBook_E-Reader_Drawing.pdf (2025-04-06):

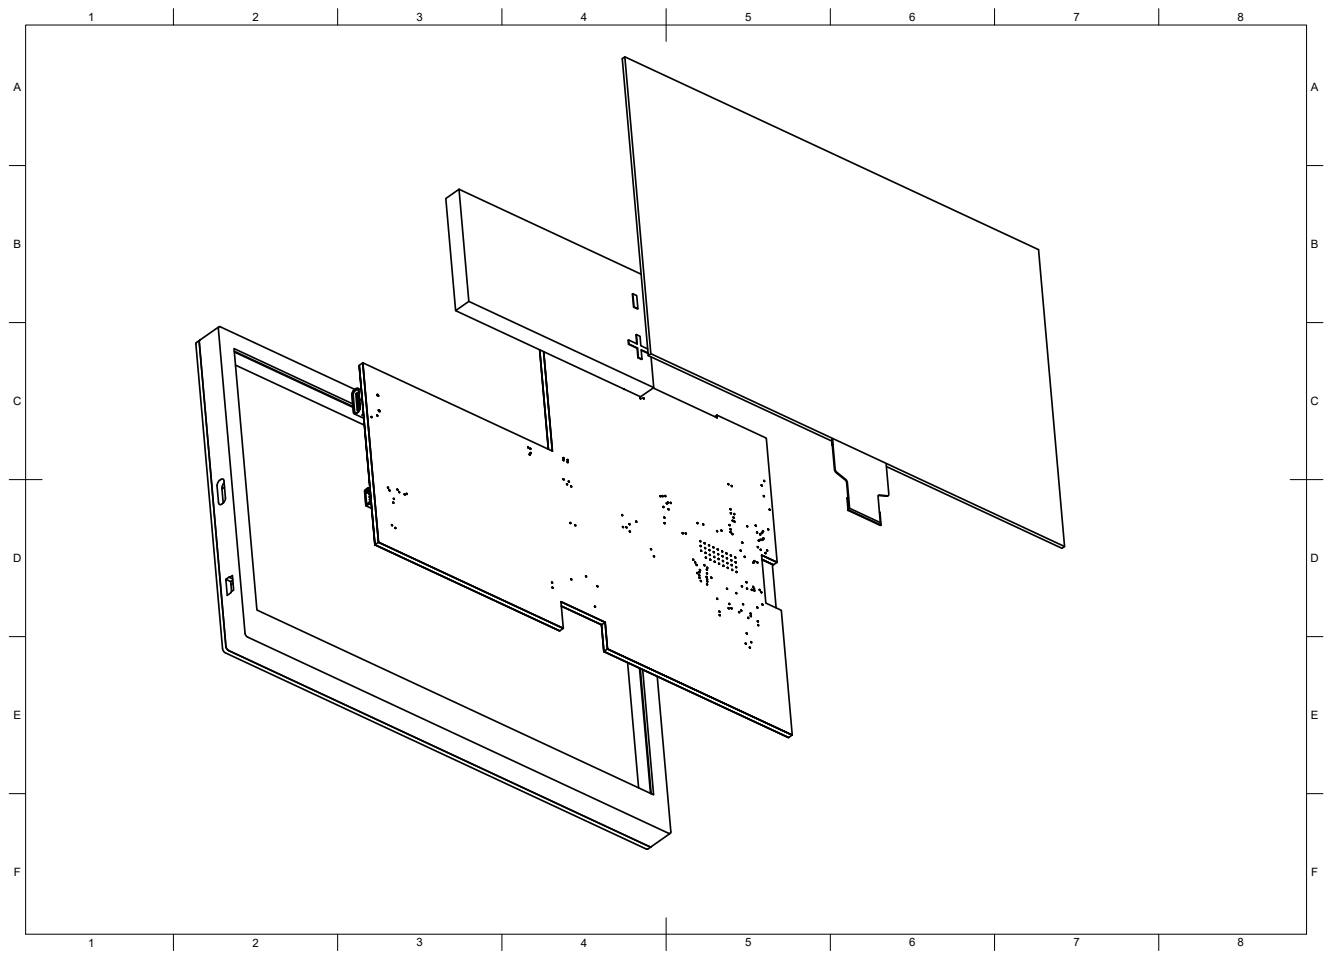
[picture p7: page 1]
8 BCDEF; ABCDEF

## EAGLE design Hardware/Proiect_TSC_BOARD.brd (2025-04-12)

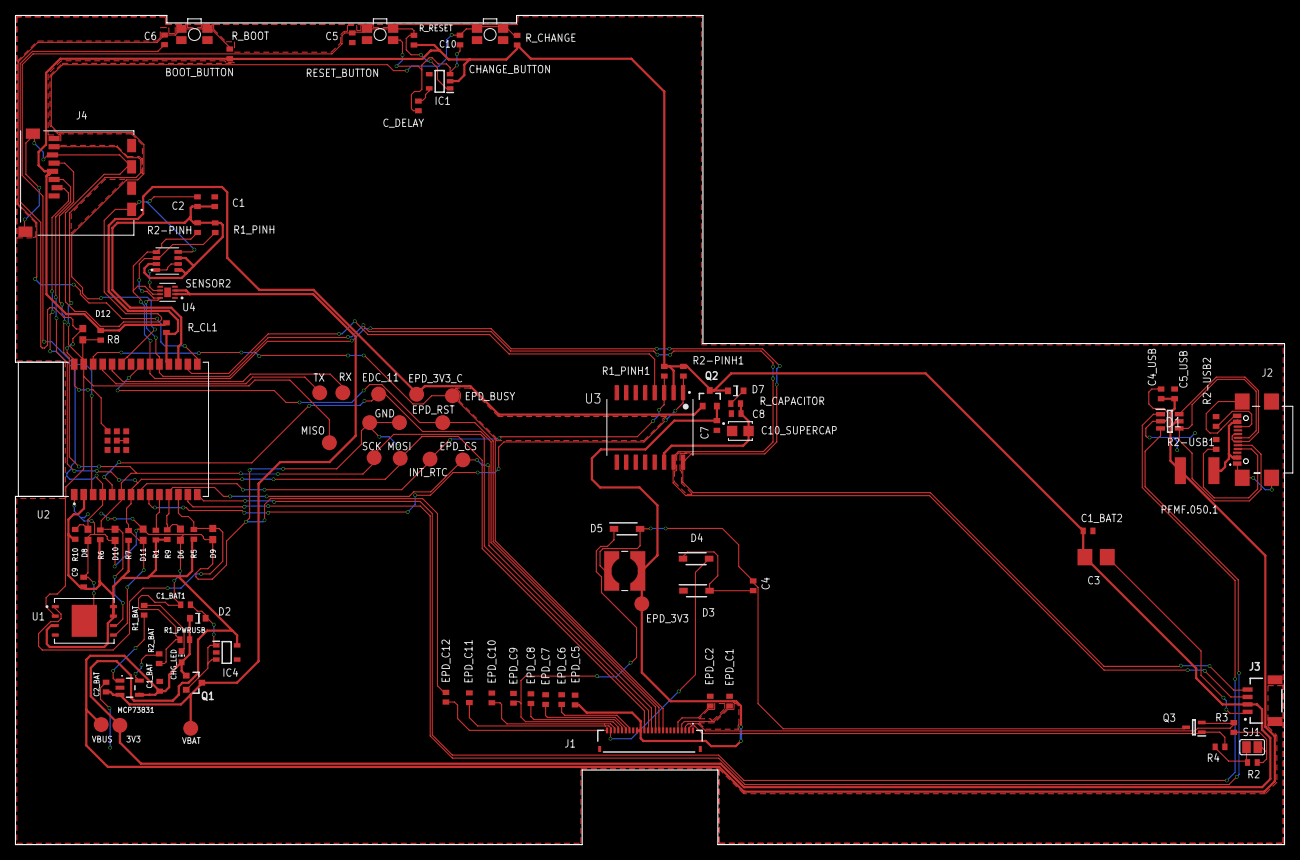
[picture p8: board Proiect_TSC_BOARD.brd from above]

Board: 2 copper layers, 170.2 x 111.2 mm, 103 parts (0 on the bottom side), 55 nets.

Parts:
3V3: TPTP20R; TP20R
BOOT_BUTTON: BUTTON_CUSYOMV1; MYBUTTON
C1, C2, C6, C8, C9, C10: 100nF; ESP32_WROVER_EAGLE-LTSPICE_C0402
C1_BAT, C1_BAT1, C1_BAT2, C2_BAT: 4.7uF; ESP32_WROVER_EAGLE-LTSPICE_C0402
C3: 100uF; RCL_CT3528
C4: 4.7uF/25V; ESP32_WROVER_EAGLE-LTSPICE_C0402
C4_USB: 100nF; EAGLE-LTSPICE_C0402
C5: 1uF; ESP32_WROVER_EAGLE-LTSPICE_C0402
C5_USB: 4.7uF; EAGLE-LTSPICE_C0402
C7: 10uF; ESP32_WROVER_EAGLE-LTSPICE_C0402
C10_SUPERCAP: CPH3225A; CAPCP3225X100N
CHANGE_BUTTON: CHANGE_BUTTON; MYBUTTON
CHG_LED: ADAFRUIT_CHIP-LED0603
C_DELAY: 100nF; ESP32_WROVER_EAGLE-LTSPICE_C0402
D1: USBLC6-2SC6Y; SOT95P280X145-6N
D2: ESP32_WROVER_AVX---SD0805S020S1R0_AVX_SD0805S020S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; ESP32_WROVER_AVX---SD0805S020S1R0_AVX_SD0805S020S1R0_0
D3, D4, D5: MBR0530; SOD3716X135N
D6, D8, D9, D10, D11, D12: PGB1010603MR; DIOC1608X36N
D7: SD0805S020S1R0; ESP32_WROVER_AVX---SD0805S020S1R0_AVX_SD0805S020S1R0_0
EDC_11: TPTP20R; TP20R
EPD_3V3, EPD_3V3_C: TPTP20R; TP20R
EPD_BUSY: TPTP20R; TP20R
EPD_C1, EPD_C2, EPD_C6, EPD_C7, EPD_C8, EPD_C9, EPD_C10, EPD_C11, EPD_C12: 1uF/50V; ESP32_WROVER_EAGLE-LTSPICE_C0402
EPD_C5: 0.1uF/50V; ESP32_WROVER_EAGLE-LTSPICE_C0402
EPD_CS: TPTP20R; TP20R
EPD_RST: TPTP20R; TP20R
GND: TPTP20R; TP20R
IC1: BD5229G-TR; SOT95P280X125-5N
IC4: XC6220A331MR-G; SOT95P280X120-5N
INT_RTC: TPTP20R; TP20R
J1: FH34SRJ-24S-0.5SH_99_; FH34SRJ24S05SH99
J2: SAMACSYS_PARTS_USB4110-GF-A; SAMACSYS_PARTS_USB4110GFA
J3: QWIIC_RIGHT_ANGLE; JST04_1MM_RA
J4: 112A-TAAR-R03_ATTEND; 112ATAARR03ATTEND
L1: 68uH; IND_4828-WE-TPC_WRE
MCP73831: MCP73831; ESP32_WROVER_SPARKFUN-IC-POWER_SOT23-5
MISO: TPTP20R; TP20R
MOSI: TPTP20R; TP20R
PFMF.050.1: ESP32C6_VARISTORCN1812; ESP32C6_VARISTOR_CT/CN1812
Q1, Q2: 20V/4.2A/52mΩ/1.4W; ESP32_WROVER_SPARKFUN-DISCRETESEMI_SOT23-3
Q3: SI1308EDL-T1-GE3; SOT65P210X110-3N
R1, R1_PINH, R1_PINH1, R2-PINH, R2-PINH1, R4, R5, R6, R7, R8, R9, R10: 10K; ESP32_WROVER_EAGLE-LTSPICE_R0402
R1_BAT: 200; ESP32_WROVER_EAGLE-LTSPICE_R0402
R1_PWRUSB: 100K; ESP32_WROVER_EAGLE-LTSPICE_R0402
R2: 2.2; ESP32_WROVER_EAGLE-LTSPICE_R0402
R2-USB1, R2-USB2: 5k1; ESP32_WROVER_EAGLE-LTSPICE_R0402
R2_BAT: 2K; ESP32_WROVER_EAGLE-LTSPICE_R0402
R3: 0.47; ESP32_WROVER_EAGLE-LTSPICE_R0402
RESET_BUTTON: BUTTON_CUSYOMV1; MYBUTTON
RX: TPTP20R; TP20R
R_BOOT: 10K; ESP32_WROVER_EAGLE-LTSPICE_R0402
R_CAPACITOR: 15; ESP32_WROVER_EAGLE-LTSPICE_R0402
R_CHANGE: 10K; ESP32_WROVER_EAGLE-LTSPICE_R0402
R_CL1: 10K; ESP32_WROVER_EAGLE-LTSPICE_R0402
R_RESET: 10K; ESP32_WROVER_EAGLE-LTSPICE_R0402
SCK: TPTP20R; TP20R
SENSOR2: BME688; ESP32_WROVER_BME680_PSON80P300X300X100-8N
SJ1: 0; SJ
TP5: TPTP20R; TP20R
TX: TPTP20R; TP20R
U1: W25Q512JVEIQ; SON127P600X800X80-9N
U2: ESP32-C6-WROOM-1-N8; XCVR_ESP32-C6-WROOM-1-N8
U3: DS3231SN#; SOIC127P1032X265-16N
U4: MAX17048G+T10; SON50P200X200X80-9N
VBAT: TPTP20R; TP20R
VBUS: TPTP20R; TP20R

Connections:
3V3: 3V3.TP, C1_BAT2.1, C3.+, C9.1, D7.2, IC1.2, IC4.5, J3.2, J4.P4, Q2.3, R1.2, R1_PINH1.2, R2-PINH1.2, R5.2, R6.2, R7.2, R8.2, R9.2, R10.2, R_BOOT.2, R_CHANGE.2, R_CL1.2, R_RESET.2, U1.3, U1.7, U1.8, U2.2, U3.2
32KHZ: R2-PINH1.1, U2.9, U3.1
DN: D1.4, J2.A7, J2.B7
DP: D1.6, J2.A6, J2.B6
EPD_3V3: C7.1, EPD_3V3.TP, EPD_C5.2, J1.15, J1.16, L1.2, Q2.2
EPD_3V3_C: EPD_3V3_C.TP, Q2.1, R_CL1.1, U2.18
EPD_BUSY: EPD_BUSY.TP, J1.9, U2.26
EPD_CS: D6.2, EPD_CS.TP, J1.12, R9.1, U2.11
EPD_DC: EDC_11.TP, J1.11, U2.5
EPD_RST: EPD_RST.TP, J1.10, U2.21
FLASH_CS: D9.2, R5.1, U1.1, U2.12
GDR: J1.2, Q3.1, R4.2
GND: BOOT_BUTTON.1, BOOT_BUTTON.2, C1.2, C1_BAT.2, C1_BAT1.2, C1_BAT2.2, C2.2, C2_BAT.2, C3.-, C4_USB.2, C5.2, C5_USB.2, C6.2, C7.2, C8.2, C9.2, C10.2, C10_SUPERCAP.1, CHANGE_BUTTON.1, CHANGE_BUTTON.2, C_DELAY.2, D1.2, D3.1, D6.1, D8.1, D9.1, D10.1, D11.1, D12.1, EPD_C1.2, EPD_C2.2, EPD_C5.1, EPD_C6.2, EPD_C7.2, EPD_C8.2, EPD_C9.2, EPD_C10.2, EPD_C11.2, EPD_C12.2, GND.TP, IC1.3, IC4.2, J1.8, J1.17, J1.MP1, J1.MP2, J2.A1, J2.A12, J2.B1, J2.B12, J2.MP1, J2.MP2, J2.MP3, J2.MP4, J3.1, J4.G1, J4.G2, J4.G3, J4.G4, J4.P6, MCP73831.2, R1_PWRUSB.1, R2.1, R2-USB1.1, R2-USB2.2, R2_BAT.1, R4.1, RESET_BUTTON.1, RESET_BUTTON.2, SENSOR2.1, SENSOR2.5, SENSOR2.7, SJ1.1, TP5.TP, U1.4, U1.9, U2.1, U2.28, U2.29_1, U2.29_2, U2.29_3, U2.29_4, U2.29_5, U2.29_6, U2.29_7, U2.29_8, U2.29_9, U3.13, U4.1, U4.4, U4.6, U4.9
GPIO8: R1.1, U2.10
I2C_PW: C1.1, C2.1, R1_PINH.2, R2-PINH.2, SENSOR2.2, SENSOR2.6, SENSOR2.8, U2.17
INT_RTC: INT_RTC.TP, R1_PINH1.1, U2.8, U3.3
IO/BOOT: BOOT_BUTTON.3, BOOT_BUTTON.4, C6.1, R_BOOT.1, U2.15
IO/CHANGE: C10.1, CHANGE_BUTTON.3, CHANGE_BUTTON.4, R_CHANGE.1, U2.23
MISO: D12.2, J4.P7, MISO.TP, R8.1, U1.2, U2.27
MOSI: D11.2, J1.14, J4.P3, MOSI.TP, R7.1, U1.5, U2.7
unnamed: J2.A5, R2-USB1.2
unnamed: J2.B5, R2-USB2.1
unnamed: C1_BAT1.1, D2.1, IC4.1, IC4.3, Q1.2
unnamed: C4.1, D3.2, D4.1
unnamed: CHG_LED.C, R1_BAT.1
unnamed: MCP73831.1, R1_BAT.2
unnamed: MCP73831.5, R2_BAT.2
unnamed: EPD_C1.1, J1.4
unnamed: EPD_C2.1, J1.5
unnamed: EPD_C6.1, J1.18
unnamed: EPD_C7.1, J1.19
unnamed: EPD_C8.1, J1.20
unnamed: EPD_C10.1, J1.22
unnamed: EPD_C12.1, J1.24
unnamed: C_DELAY.1, IC1.5
unnamed: D7.1, R_CAPACITOR.2
PREVGH: D5.1, EPD_C9.1, J1.21
PREVGL: D4.2, EPD_C11.1, J1.23
RESE: J1.3, Q3.2, R3.2
RESE': R2.2, R3.1, SJ1.2
RESET: C5.1, IC1.1, RESET_BUTTON.3, RESET_BUTTON.4, R_RESET.1, U2.3
RTC_RST: U2.16, U3.4
RX: RX.TP, U2.24
SCK: D10.2, J1.13, J4.P5, R6.1, SCK.TP, U1.6, U2.6
SCL: J3.4, R2-PINH.1, SENSOR2.4, U2.20, U3.16, U4.7
SDA: J3.3, R1_PINH.1, SENSOR2.3, U2.19, U3.15, U4.8
SRC: C4.2, D5.2, L1.1, Q3.3
SS_SD: D8.2, J4.P2, R10.1, U2.4
TX: TX.TP, U2.25
USB_D+: D1.1, U2.14
USB_D-: D1.3, U2.13
VBAT: C2_BAT.1, MCP73831.3, Q1.3, U4.2, U4.3, VBAT.TP
VBUS: C1_BAT.1, C4_USB.1, C5_USB.1, CHG_LED.A, D1.5, D2.2, MCP73831.4, PFMF.050.1.2, Q1.1, R1_PWRUSB.2, VBUS.TP
VRTC: C8.1, C10_SUPERCAP.2, R_CAPACITOR.1, U3.14
VUSB: J2.A4, J2.A9, J2.B4, J2.B9, PFMF.050.1.1

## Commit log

2025-04-06 Added 3D model of the device
2025-04-12 Delete Hardware/Proiect_TSC_2025.brd
    Deleted old version of this file.
    [Proiect_TSC_2025.brd]
2025-04-12 Delete Hardware/Proiect_TSC_2025.sch
    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
    [Proiect_TSC_2025.sch]
2025-04-12 Add files via upload
    Added the new modified files according to the review.
    [Proiect_TSC_BOARD.brd, Proiect_TSC_SCHEMATIC.sch]
2025-04-12 Update and rename PnP_Proiect_TSC_2025_NEW v41_front.csv to Pick and Place.csv
    [Pick and Place.csv]
2025-04-12 Rename Proiect_TSC_2025_NEW v41.csv to Bill of Materials.csv
    [Bill of Materials.csv]
2025-04-12 Delete images/3D_board_front.png
    Deleted this picture because it doesnt correspond with the new version of the board.
2025-04-12 Update README.md
    Added BOM table and block diagram

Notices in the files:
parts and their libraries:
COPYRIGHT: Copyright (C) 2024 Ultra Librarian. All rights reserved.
